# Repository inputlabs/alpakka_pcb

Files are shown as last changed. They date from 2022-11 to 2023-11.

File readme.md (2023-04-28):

# Alpakka PCB

*Alpakka controller Printed Circuit Board reference design*

## Project links
- [Alpakka Manual](https://inputlabs.io/devices/alpakka/manual).
- [Alpakka Firmware](https://github.com/inputlabs/alpakka_firmware).
- [Alpakka PCB](https://github.com/inputlabs/alpakka_pcb). _(you are here)_
- [Alpakka 3D-print](https://github.com/inputlabs/alpakka_case).
- [Input Labs Roadmap](https://github.com/orgs/inputlabs/projects/2/views/2).

## Previews

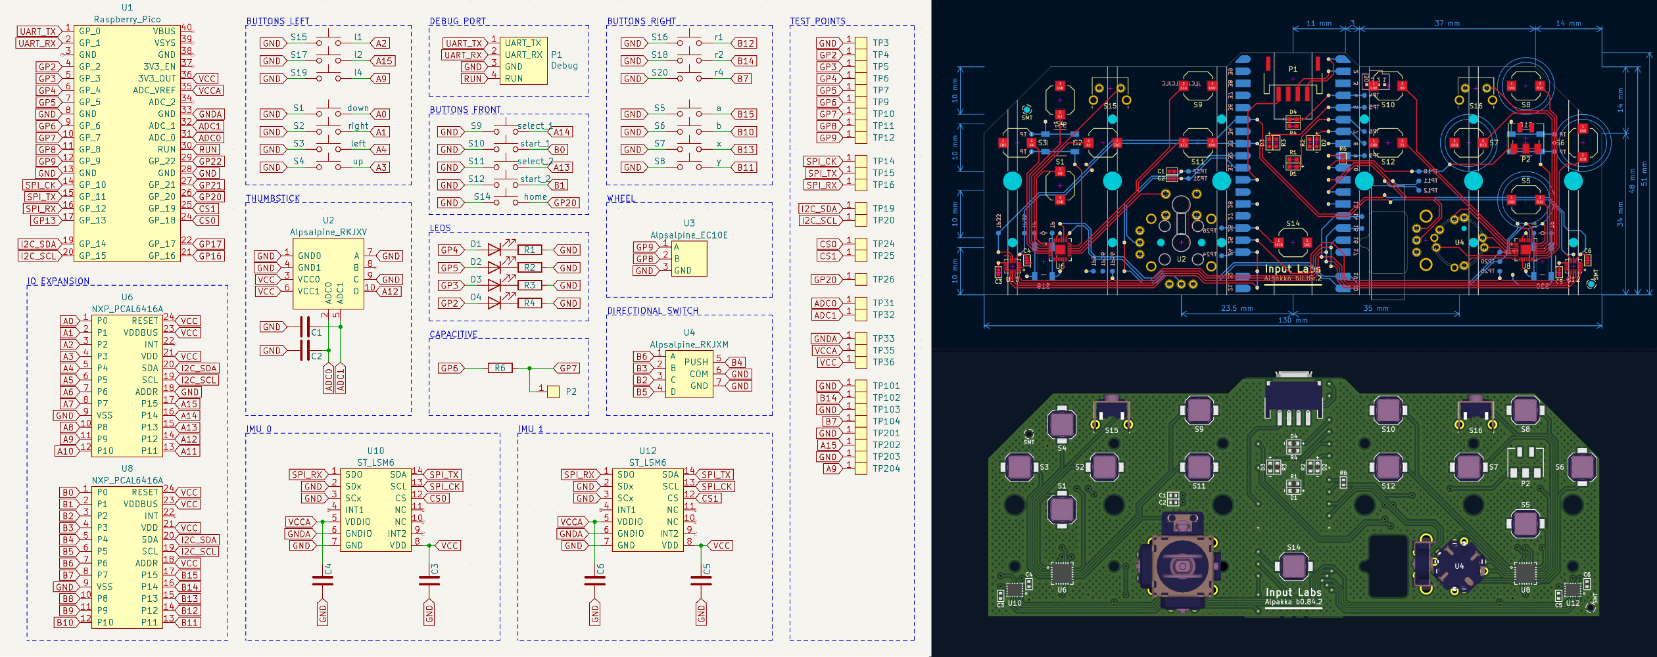
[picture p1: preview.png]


## Order a PCB from the reference design
For ordering a reference design PCB (with no modifications) is possible to use the pre-built [order files](https://github.com/inputlabs/alpakka_pcb/releases). Check the [manual](https://inputlabs.io/devices/alpakka/manual/diy_pcb) for step-by-step instructions.

## Modify the schematics and PCB

### Dependencies
- [KiCad 7](https://www.kicad.org)

### Change components for SMT pick & place

- Open `.kicad_sch` file in Schematics editor.
- Go to menu `Tools` → `Edit symbol fields`
- Group by field `Group`
- Change id references (`LCSC id` for [JLCPCB](https://jlcpcb.com)).

### Generate order files from sources
- Copy `plugins/kicad_ilo_export.py` into KiCad plugins folder (PCB editor → menu `Tools` → `External plugins` → `Reveal plugins folder`).
- Open `.kicad_pcb` file in PCB editor.
- Use menu `Edit` → `Fill all zones`
- Go to menu `Tools` → `External plugins` → `Refresh plugins`
- Go to menu `Tools` → `External plugins` → `Input Labs: export`
- Files are generated into `order/`

### If the plugin does not load correctly
- Open `Preferences` → `Action plugins`
- Check that the plugin is installed correctly / check errors.

### Procedural zones
Consolidated zones increase `.kicad_pcb` file size significantly, so instead is recommended to load and save the project without consolidation:

- After loading the PCB project: `Edit` → `Fill all zones`.
- Before saving the PCB project: `Edit` → `Unfill all zones`.

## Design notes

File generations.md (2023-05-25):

# PCB generations

The concept of `Generation` versioning was introduced to mark minor changes that are still relevant for the firmware execution, so the firmware can use different configuration values or execution paths if needed.

This way a single unified version of the firmware is able to support multiple versions of the PCB if the changes are not big backward compatibility breakers.

These firmware-relevant changes may be different in size and complexity than the actual changes in PCB layout or components, and therefore are tracked separately from the main PCB semantic versioning.

## Generations

| Generation  | From PCB version | To PCB version | FW-relevant change |
| - | - | - | - |
| 0  | b0.0.0 | b0.84.4 | |
| 1  | b0.88.0 | ONGOING | 100KΩ -> 500KΩ touch resistor |

## Masking

The firmware can check in execution-time to which generation the PCB belongs via a ternary mask on the first IO expander unused pins.

| Electrical | Ternary value |
| - | - |
| FLOAT | 0 |
| GND | 1 |
| VCC | 2 |

| Ternary mask index | 3 | 2 | 1 | 0 |
| - | - | - | - | - |
| **Pin** | - | - | A10 | A11 |

| Generation  | A10 | A11 |
| - | - | - |
| 0 | FLOAT | FLOAT |
| 1 | FLOAT | GND |

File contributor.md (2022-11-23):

# Contributor Agreement

## Human-readable summary

The TLDR of the agreement is:

- You confirm that you are the author of the contributions you are submitting.
- You retain the copyright of your contributions, but you give us permission to use such contributions without restrictions.
- You won't use any additional terms or patents against us.
- We will always keep your contributions under the current license, or some other open source license.

This summary (content before Section 0) is not part of the agreement, and it is NOT legally binding. It may be incomplete or even incorrect. It does not in any case override the actual legal terms defined below. Keep reading for the actual legal terms.

## 0. Preface
Thank you for your interest in contributing to Input Labs ("We" or "Us").

This contributor agreement ("Agreement") documents the rights granted by contributors to Us. To make this document effective, please follow the instructions at Section 7.2. This is a legally binding document (Sections 0 and subsequent), so please read it carefully before agreeing to it. The Agreement may cover more than one software project managed by Us.

## 1. Definitions
"You" (as Individual) means the individual who Submits a Contribution to Us.

"You" (as Entity) means any Legal Entity on behalf of whom a Contribution has been received by Us. "Legal Entity" means an entity which is not a natural person. "Affiliates" means other Legal Entities that control, are controlled by, or under common control with that Legal Entity. For the purposes of this definition, "control" means (i) the power, direct or indirect, to cause the direction or management of such Legal Entity, whether by contract or otherwise, (ii) ownership of fifty percent (50%) or more of the outstanding shares or securities which vote to elect the management or other persons who direct such Legal Entity or (iii) beneficial ownership of such entity.

"Contribution" means any work of authorship that is Submitted by You to Us in which You own or assert ownership of the Copyright. If You do not own the Copyright in the entire work of authorship, please follow the instructions in Section 7.1.

"Copyright" means all rights protecting works of authorship owned or controlled by You [or Your Affiliates], including copyright, moral and neighboring rights, as appropriate, for the full term of their existence including any extensions by You.

"Material" means the work of authorship which is made available by Us to third parties. When this Agreement covers more than one software project, the Material means the work of authorship to which the Contribution was Submitted. After You Submit the Contribution, it may be included in the Material.

"Submit" means any form of electronic, verbal, or written communication sent to Us or our representatives, including but not limited to electronic mailing lists, source code control systems, and issue tracking systems that are managed by, or on behalf of, Us for the purpose of discussing and improving the Material, but excluding communication that is conspicuously marked or otherwise designated in writing by You as "Not a Contribution."

"Submission Date" means the date on which You Submit a Contribution to Us.

"Effective Date" means the date You execute this Agreement or the date You first Submit a Contribution to Us, whichever is earlier.

"Media" means any portion of a Contribution which is not software.

## 2. Grant of Rights

### 2.1 Copyright License
(a) You retain ownership of the Copyright in Your Contribution and have the same rights to use or license the Contribution which You would have had without entering into the Agreement.

(b) To the maximum extent permitted by the relevant law, You grant to Us a perpetual, worldwide, non-exclusive, transferable, royalty-free, irrevocable license under the Copyright covering the Contribution, with the right to sublicense such rights through multiple tiers of sublicensees, to reproduce, modify, display, perform and distribute the Contribution as part of the Material; provided that this license is conditioned upon compliance with Section 2.3.

### 2.1 Copyright Assignment
(a) At the time the Contribution is Submitted, You assign to Us all right, title, and interest worldwide in all Copyright covering the Contribution; provided that this transfer is conditioned upon compliance with Section 2.3.

(b) To the extent that any of the rights in Section 2.1(a) cannot be assigned by You to Us, You grant to Us a perpetual, worldwide, exclusive, royalty-free, transferable, irrevocable license under such non-assigned rights, with rights to sublicense through multiple tiers of sublicensees, to practice such non-assigned rights, including, but not limited to, the right to reproduce, modify, display, perform and distribute the Contribution; provided that this license is conditioned upon compliance with Section 2.3.

(c) To the extent that any of the rights in Section 2.1(a) can neither be assigned nor licensed by You to Us, You irrevocably waive and agree never to assert such rights against Us, any of our successors in interest, or any of our licensees, either direct or indirect; provided that this agreement not to assert is conditioned upon compliance with Section 2.3.

(d) Upon such transfer of rights to Us, to the maximum extent possible, We immediately grant to You a perpetual, worldwide, non-exclusive, royalty-free, transferable, irrevocable license under such rights covering the Contribution, with rights to sublicense through multiple tiers of sublicensees, to reproduce, modify, display, perform, and distribute the Contribution. The intention of the parties is that this license will be as broad as possible and to provide You with rights as similar as possible to the owner of the rights that You transferred. This license back is limited to the Contribution and does not provide any rights to the Material.

### 2.2 Patent License
For patent claims including, without limitation, method, process, and apparatus claims which You [or Your Affiliates] own, control or have the right to grant, now or in the future, You grant to Us a perpetual, worldwide, non-exclusive, transferable, royalty-free, irrevocable patent license, with the right to sublicense these rights to multiple tiers of sublicensees, to make, have made, use, sell, offer for sale, import and otherwise transfer the Contribution and the Contribution in combination with the Material (and portions of such combination). This license is granted only to the extent that the exercise of the licensed rights infringes such patent claims; and provided that this license is conditioned upon compliance with Section 2.3.

### 2.3 Outbound License
As a condition on the grant of rights in Sections 2.1 and 2.2, We agree to license the Contribution only under the terms of the license or licenses which We are using on the Submission Date for the Material or any licenses which are approved by the Open Source Initiative on or after the Effective Date, including both permissive and copyleft licenses, whether or not such licenses are subsequently disapproved (including any right to adopt any future version of a license if permitted).

### 2.4 Moral Rights
If moral rights apply to the Contribution, to the maximum extent permitted by law, You waive and agree not to assert such moral rights against Us or our successors in interest, or any of our licensees, either direct or indirect.

### 2.5 Our Rights
You acknowledge that We are not obligated to use Your Contribution as part of the Material and may decide to include any Contribution We consider appropriate.

### 2.6 Reservation of Rights
Any rights not expressly [assigned or] licensed under this section are expressly reserved by You.

## 3. Agreement
You confirm that:

(a) You have the legal authority to enter into this Agreement.

(b) You [or Your Affiliates] own the Copyright and patent claims covering the Contribution which are required to grant the rights under Section 2.

(c-1) (as Individual) The grant of rights under Section 2 does not violate any grant of rights which You have made to third parties, including Your employer. If You are an employee, You have had Your employer approve this Agreement or sign the Entity version of this document. If You are less than eighteen years old, please have Your parents or guardian sign the Agreement.

(c-2) (as Entity) The grant of rights under Section 2 does not violate any grant of rights which You or Your Affiliates have made to third parties.

(d) You have followed the instructions in Section 7.1, if You do not own the Copyright in the entire work of authorship Submitted.

## 4. Disclaimer
EXCEPT FOR THE EXPRESS WARRANTIES IN SECTION 3, THE CONTRIBUTION IS PROVIDED "AS IS". MORE PARTICULARLY, ALL EXPRESS OR IMPLIED WARRANTIES INCLUDING, WITHOUT LIMITATION, ANY IMPLIED WARRANTY OF MERCHANTABILITY, FITNESS FOR A PARTICULAR PURPOSE AND NON-INFRINGEMENT ARE EXPRESSLY DISCLAIMED BY YOU TO US [AND BY US TO YOU]. TO THE EXTENT THAT ANY SUCH WARRANTIES CANNOT BE DISCLAIMED, SUCH WARRANTY IS LIMITED IN DURATION TO THE MINIMUM PERIOD PERMITTED BY LAW.

## 5. Consequential Damage Waiver
TO THE MAXIMUM EXTENT PERMITTED BY APPLICABLE LAW, IN NO EVENT WILL YOU [OR US] BE LIABLE FOR ANY LOSS OF PROFITS, LOSS OF ANTICIPATED SAVINGS, LOSS OF DATA, INDIRECT, SPECIAL, INCIDENTAL, CONSEQUENTIAL AND EXEMPLARY DAMAGES ARISING OUT OF THIS AGREEMENT REGARDLESS OF THE LEGAL OR EQUITABLE THEORY (CONTRACT, TORT OR OTHERWISE) UPON WHICH THE CLAIM IS BASED.

## 6. Miscellaneous

### 6.1 Accordance
This Agreement will be governed by and construed in accordance with the laws of Finland (European Union) excluding its conflicts of law provisions. Under certain circumstances, the governing law in this section might be superseded by the United Nations Convention on Contracts for the International Sale of Goods ("UN Convention") and the parties intend to avoid the application of the UN Convention to this Agreement and, thus, exclude the application of the UN Convention in its entirety to this Agreement.

### 6.2 Overrides
This Agreement sets out the entire agreement between You and Us for Your Contributions to Us and overrides all other agreements or understandings.

### 6.3 Third Parties
If You or We assign the rights or obligations received through this Agreement to a third party, as a condition of the assignment, that third party must agree in writing to abide by all the rights and obligations in the Agreement.

### 6.4 Failure
The failure of either party to require performance by the other party of any provision of this Agreement in one situation shall not affect the right of a party to require such performance at any time in the future. A waiver of performance under a provision in one situation shall not be considered a waiver of the performance of the provision in the future or a waiver of the provision in its entirety.

### 6.5 Void
If any provision of this Agreement is found void and unenforceable, such provision will be replaced to the extent possible with a provision that comes closest to the meaning of the original provision and which is enforceable. The terms and conditions set forth in this Agreement shall apply notwithstanding any failure of essential purpose of this Agreement or any limited remedy to the maximum extent possible under law.

## 7 Additional Instructions

### 7.1 Non-entire copyright ownership
If You do not own the Copyright in the entire work of authorship Submitted:
- Share details about the Copyright situation with Us.
- Wait for explicit approval from Us regarding the copyright situation before submitting your contribution.

### 7.2 Acceptance instructions

- Include the text label `#CLASIGN` in the commit message of your Pull Request.

By including such label you confirm that You read, understood, and agreed with this Contributor License Agreement, for all your contributions on projects managed by Us. You only have to do this once.

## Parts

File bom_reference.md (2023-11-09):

# Bill of materials reference

## SMD

| Component | Labels | Package | Manufacturer | Model | LCSC id |
| - | - | - | - | - | - |
| Front buttons | S1...S14 | - | Alps Alpine | SKPMAME010 | C115348
| IMUs | U10, U12 | LGA-14 | ST | LSM6DSRTR | C784817
| IO Expansions | U6, U8 | QFN-24 | NXP | PCAL6416AHF,128 | C2652287
| Capacitors | C1...C6  | 0402 | Samsung | CL05B104KO5NNNC | C1525
| Resistors | R1...R4  | 0603 | Uniroyal | 0603WAF200JT5E  | C22950
| Resistors | R6 | 0402 | Uniroyal | 0402WGF5103TCE  | C11616
| LEDs | D1...D4  | 0603 | Hubei Kento | C2290 | C2290
| Debug port | P1 | - | JST | S4B-PH-SM4-K-TB | C265332
| Connector | P2 | - | HRO | BC-25-3P | C707322

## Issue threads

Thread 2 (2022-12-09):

Suggestion: Move to 4 layer board

warlock31415, 2022-12-09:
Maybe moving to a 4 layer board might help with some of the routing and increase noise immunity. Something to think about.

riskable, 2023-01-12:
IMHO: 4-layer is totally unnecessary.  Noise shouldn't be much an issue with this board as all the components are digital (and low-speed at that).

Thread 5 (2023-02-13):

help uploaded file to jlcpcb

vipergts4509, 2023-02-13:
just recieved an email from jlcpcb and they are confused about the hole placement

"As shown below, comparing the drill diameter the drawing chart, it seems that the holes on the drill layer have been compensated, is the file used for production before? Usually,The drilling data in the original file are not integer, but now the drilling data in the file are integer, so we are confused.

Please help to confirm A or B?

A:If the file is production file, we fabricate as per this gerber without further compensation and optimization

B: If the gerber is original file, that means we will add +0.05 for NPTH and +0.15 for PTH, + 0.015mm trace width when we making production file..(Making clearance for the data of gerber file )"

przymi, 2023-02-13:
Could you share the picture they are referring to?
The files have been used by us, as well as various other people numerous times, without the need for any kind of compensation.

vipergts4509, 2023-02-13:
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

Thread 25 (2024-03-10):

Hall effect sensor thumbsticks

zsln, 2024-03-10:
I wanted to ask whether it is possible to replace the original two axis thumbsticks with hall effect thumbsticks, or if it requires additional changes in the firmware/pcb?

If additional changes are required, is it possible to expect those changes to be made in the future?

przymi, 2024-03-11:
Hi!
while the current analog stick essentially consists of two potentiometers, Hall-effect thumbsticks work on a different principle (change of voltage in a varying magnetic field). As a result, it's not as trivial as a drop-in replacements, but would also require some re-design of the PCB, as well as the firmware.
I've added it to our roadmap: https://github.com/orgs/inputlabs/projects/2/views/2?pane=issue&itemId=55982900

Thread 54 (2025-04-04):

(Request/Question) Optional Haptic Feedback in Firmware and Sourceable Components

sokkycakes, 2025-04-04:
What would it take to add support for haptic feedback into the firmware? The Steam Controller, Steam Deck, and Nintendo Switch Pro Controller in my experience leverage it to help with gyro feedback, as well as with capacitive touch feedback. This can also be used for alternate operation of thumbsticks as digital 4/8 way sticks to simulate the feeling of "notches" or a "gate".

The intention is that while the controller is perfectly functional right now and isn't a critical feature, I still think it would be a welcome option for people who would want to have a more complete experience catered to their liking with feedback. Rumble support in games would also be a nice to have that would be easily worked in.

The type of module I'm referring to more specifically are haptic actuators, or the "speaker" type modules similar to what a Steam Controller, Switch JoyCon/Pro Controller, or DualSense controller has.

At the very least and at a quick search and glance, Pimoroni and Tinkersphere sell some currently cheap and easily sourceable options.
https://tinkersphere.com/arduino-compatible-components/2965-haptic-feedback-module-3v-5v.html?gQT=1
https://www.mouser.com/ProductDetail/Pimoroni/PIM452?qs=PzGy0jfpSMsfx56IL0dynA%3D%3D&mgh=1&gQT=1

przymi, 2025-04-25:
We do actually have that on our roadmap: https://github.com/inputlabs/organization/issues/11
We also experimented with small rumbler motors in the past. What it would take first and foremost, would be time.
Then we would also need additional GPIOs, so either another IO-Expander, or a different microcontroller.
All of this of course also requires changes in PCB and 3D design.

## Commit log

2022-12-23 Added BoM reference table file
2023-04-20 Upgraded project to Kicad v7
    [alpaca.kicad_pcb, alpaca.kicad_sch]
2023-04-20 Added thermal relief on VCC
    [alpaca.kicad_pcb]
2023-04-20 Fixed additional errors and warnings after moving to kicad v7
    [alpaca.kicad_pcb]
2023-04-21 Updated connections
    [alpaca.kicad_pcb]
2023-04-21 Fixed IMU VCC and VCCA being swapped
    [alpaca.kicad_pcb, alpaca.kicad_sch]
2023-04-21 Bumbed version on silkscreen
    [alpaca.kicad_pcb]
2023-04-24 Connected all push pins on the 8-directional switch
    [alpaca.kicad_pcb]
2023-04-24 Connect missing pin on the thumbstick push too
    [alpaca.kicad_pcb, alpaca.kicad_sch]
2023-04-24 Fixed API changes for using the script on Kicad 7
2023-04-25 Added hardware mask to identify PCB, Added no-connection flags to unconnected pins
    [alpaca.kicad_pcb, alpaca.kicad_sch]
2023-04-25 Rule to keepout copper under IO expander and IMUs
    [alpaca.kicad_pcb]
2023-04-26 Added basic power circuitery
    [alpaca.kicad_pcb, alpaca.kicad_sch]
2023-04-26 Added better helper drawings, to make more obvious which side the components should be soldered
    [alpaca.kicad_pcb]
2023-04-26 Changed the capacitative surface resistor to 500 KΩ
    [alpaca.kicad_pcb, alpaca.kicad_sch]
2023-04-28 Fixed filenames
    [alpakka.kicad_pcb, alpakka.kicad_sch]
2023-05-25 Added reference for PCB generations
2023-05-25 Bump version for incomming release
    [alpakka.kicad_pcb]
2023-11-09 Changed JST connector, Added Mount and Export properties, Tweaked components origins
    [alpakka.kicad_pcb, alpakka.kicad_sch]
2023-11-09 Changed JST connector in bom file
2023-12-26 Added silk labels for pico soldering
    [alpakka.kicad_pcb]
2026-11-09 Replaced connector X6511FRS-04-C85D30 with MF254RS-11-04-0743
